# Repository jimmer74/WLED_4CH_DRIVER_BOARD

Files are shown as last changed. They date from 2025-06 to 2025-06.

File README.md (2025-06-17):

# 4 Channel WS2812B WLED driver

## Disclaimer/Licence

This project (4 Channel WS2812B WLED driver - henceforth know as "The Project") is dual licenced.

If you want to use The Project for your own personal purposes (i.e. for your own use, not for financial/commercial gain), then please feel free to use and modify it as needed. No warrentee is given and no liability is assumed by me.

If you wish to use The Project, or any aspect of it, commercially please seek my permission.  I DO NOT give consent for any of the work in The Project to be used for commercial gain by others unless with my express agreement. If terms can be agreed commercially, consent will be provided by me in writing. If you do not have such consent in writing from me, you do not have the right to use The Project, or any aspect of it, commercially.

## What is this?

I wanted a custom WS2812B board, capable of driving up to 4 strips.

I have some decent Meanwell +5v high-current PSUs on hand, and this board is designed to be fed by something like that. There's a distinct lack of overcurrent protection (apart from the obvious 5mmx20mm fuse for whole board and a 5A LF resettable fuse/channel) and I'm relying on a well-made and well-specced power supply for the rest. There's no reverse voltage protection, for instance, but the PWR_IN connector is clearly marked which end is which!

A custom build of WLED including the multirelay usermod will be needed, to make this board work. I'll probably get round to updating this readme with instructions/config at some point.

If you make up a jst-xh 1x5 connector and wire it to a INMP441 microphone off-board somewhere, then you can activate the Audioreactive usermod and enjoy some beats-driven lighting.

## Board 3d Render

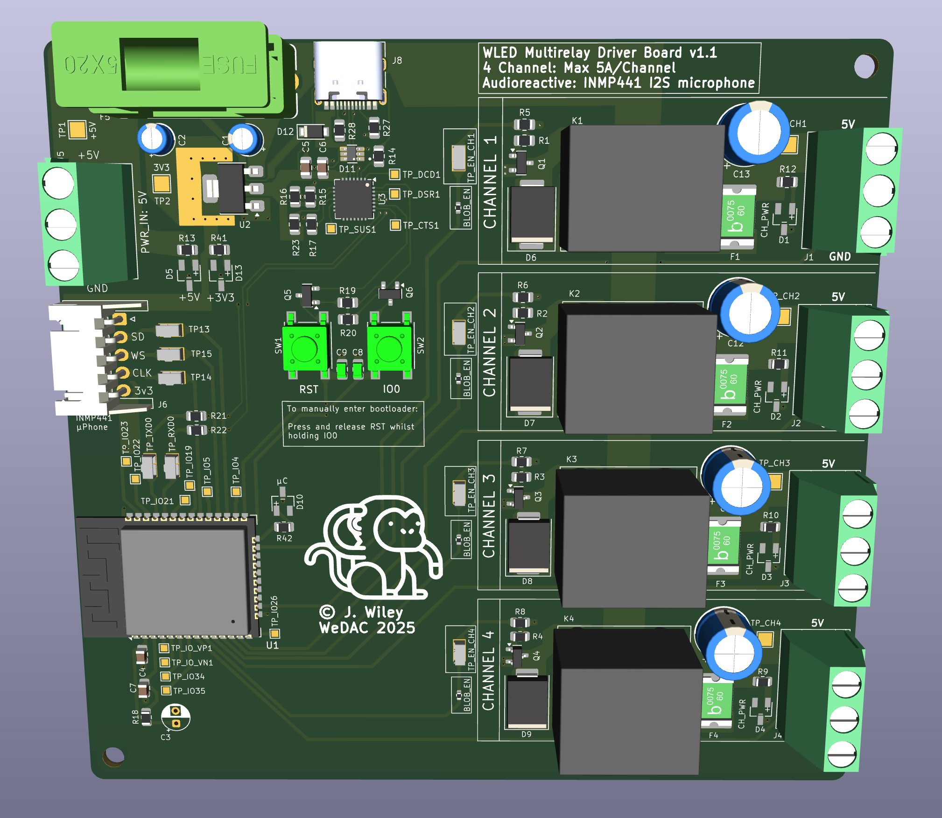
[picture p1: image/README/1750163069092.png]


## PCB Layout

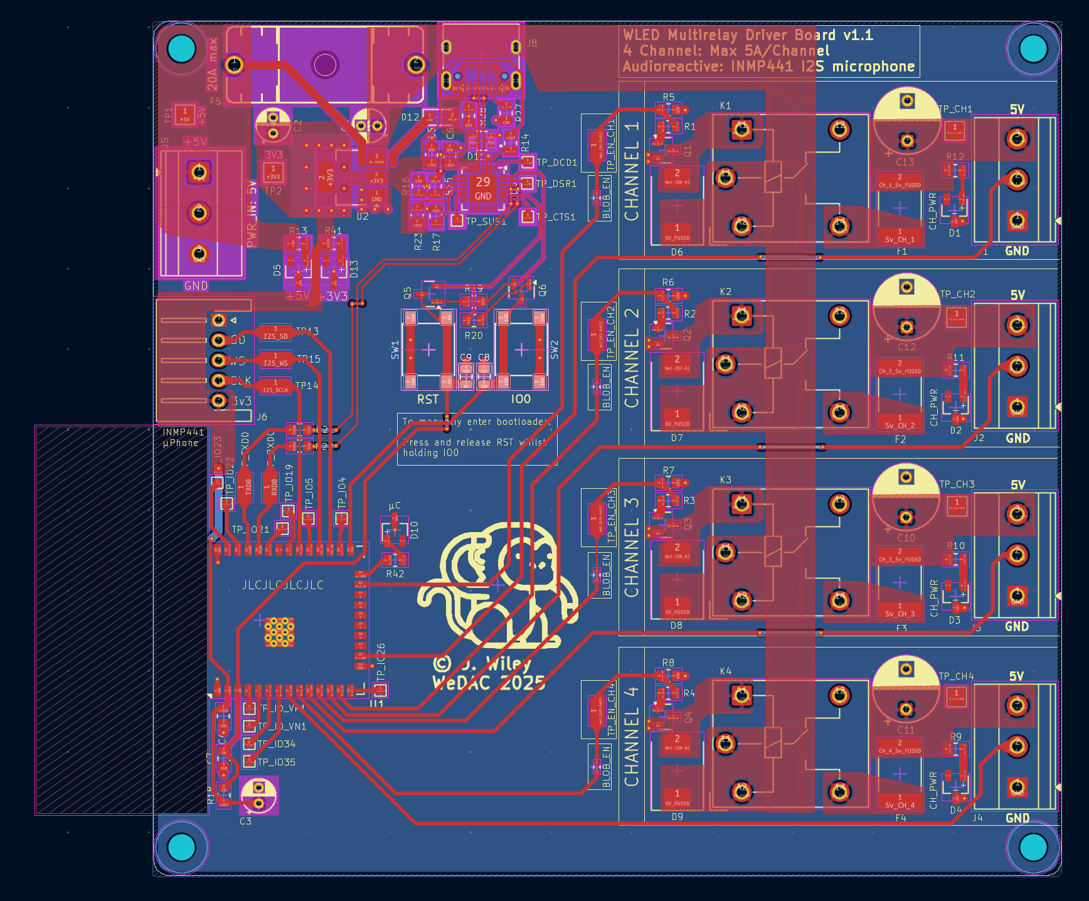
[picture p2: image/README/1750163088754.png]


## Schematic

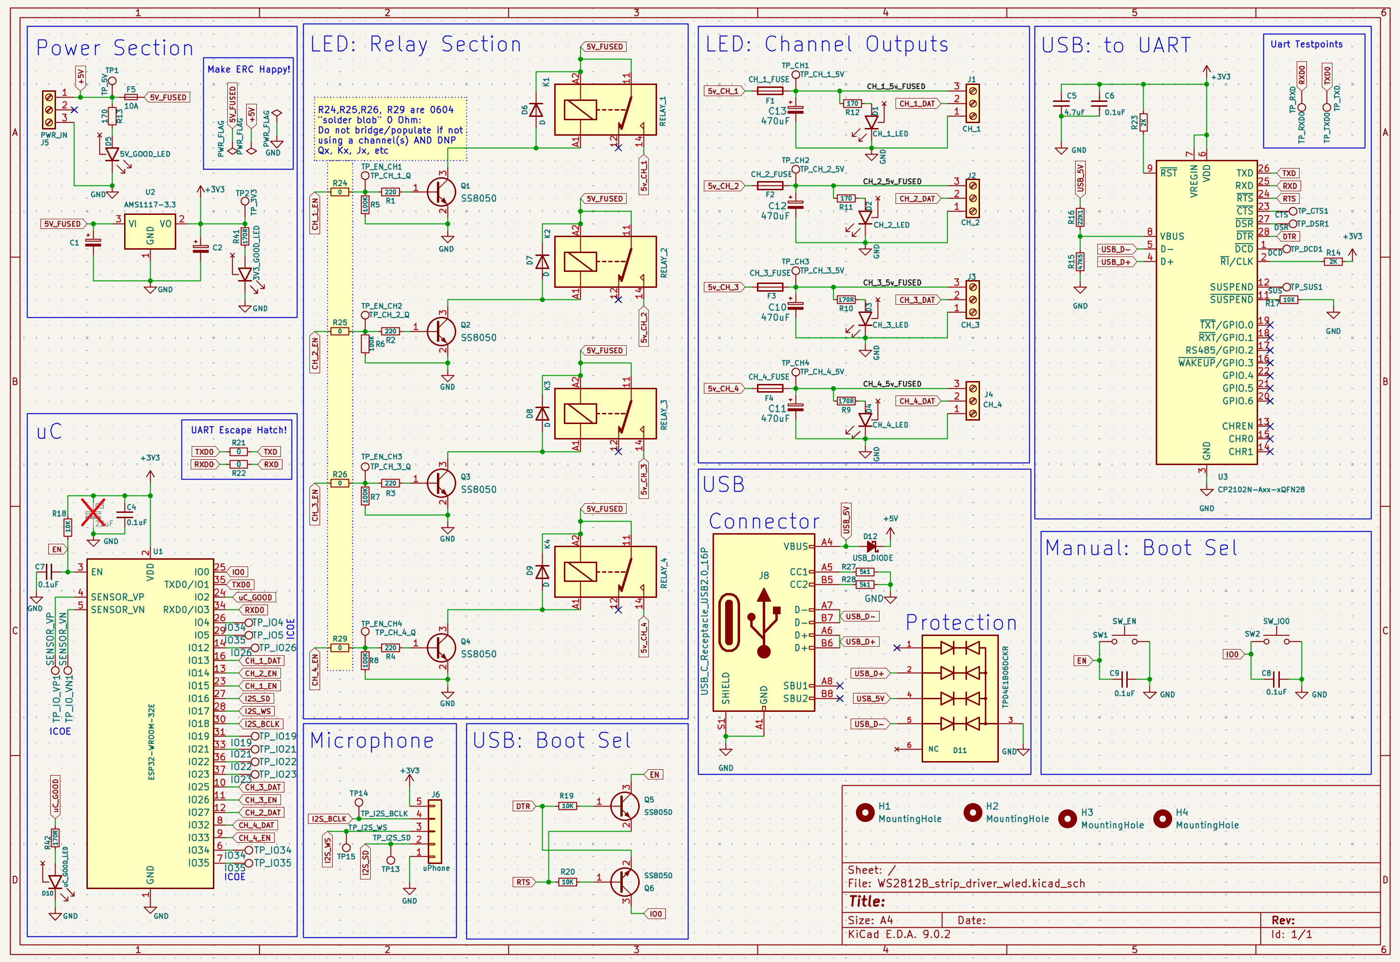
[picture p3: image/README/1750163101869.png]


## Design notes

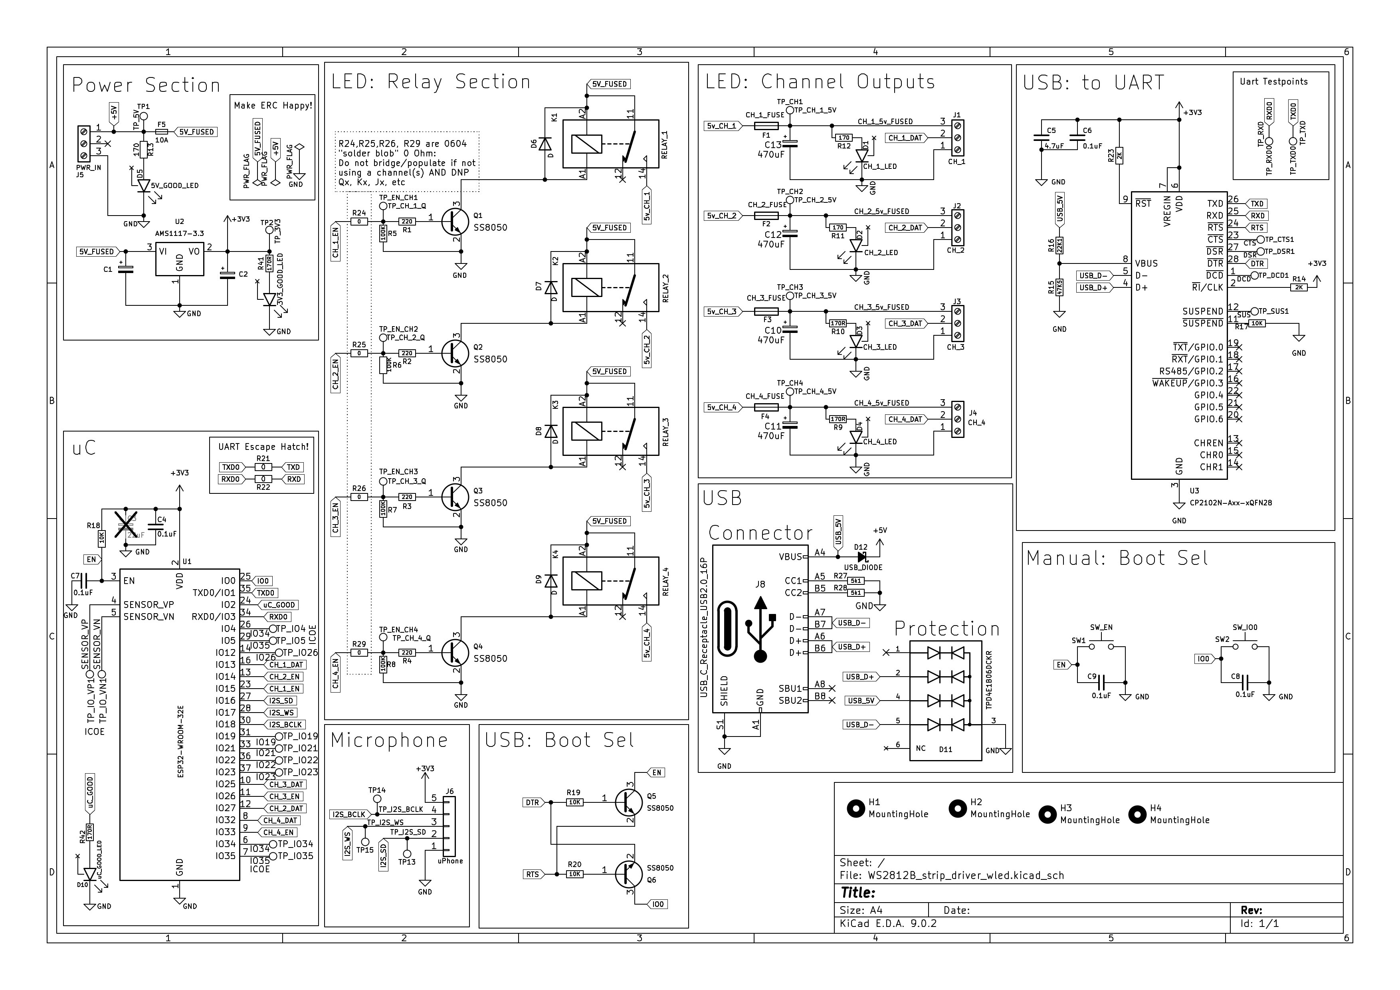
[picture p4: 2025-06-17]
wled_4ch_schematic_bnw.jpg

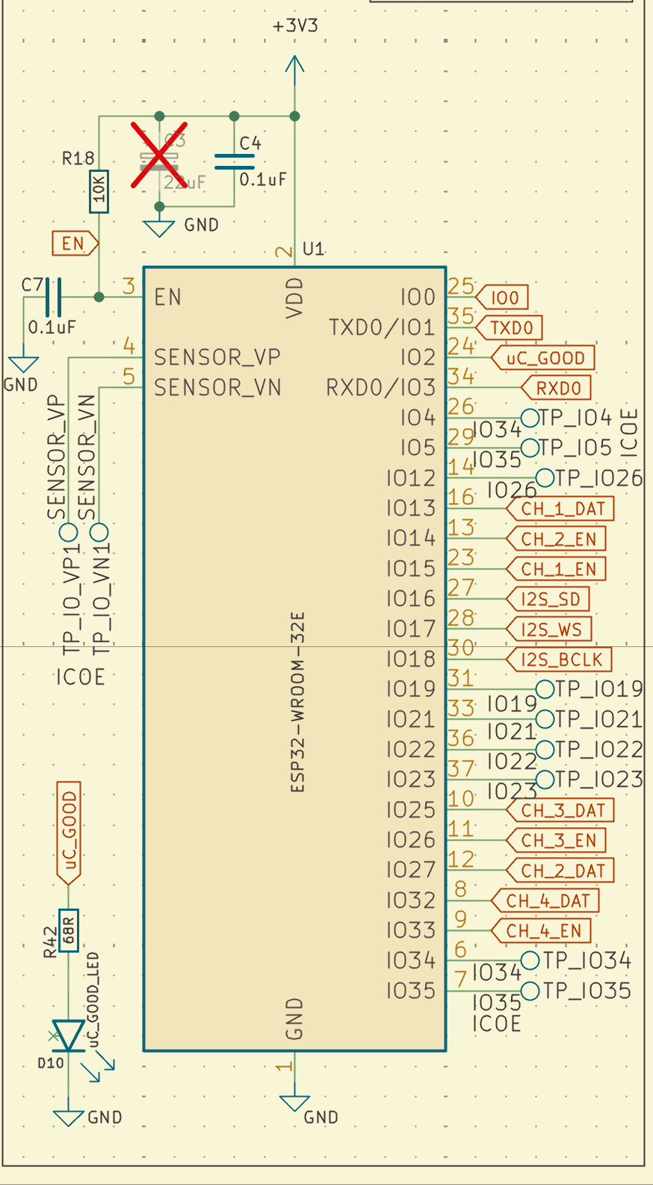
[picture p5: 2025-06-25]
wled_connections.png

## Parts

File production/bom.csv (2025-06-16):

Designator | Footprint | Quantity | Value | LCSC Part #
C1, C2 | CP_Radial_D4.0mm_P2.00mm | 2 | 22uF
C10, C11, C12, C13 | CP_Radial_D8.0mm_P5.00mm | 4 | 470uF
C4, C6, C7, C8, C9 | 0805 | 5 | 0.1uF
C5 | 0805 | 1 | 4.7uF
D1 | LED_Single_SOT23_Lumex | 1 | CH_1_LED
D10 | LED_Single_SOT23_Lumex | 1 | uC_GOOD_LED
D11 | TVS_TPD4E1B06DCKR | 1 | TPD4E1B06DCKR
D12 | Nexperia_CFP3_SOD-123W | 1 | USB_DIODE
D13 | LED_Single_SOT23_Lumex | 1 | 3V3_GOOD_LED
D2 | LED_Single_SOT23_Lumex | 1 | CH_2_LED
D3 | LED_Single_SOT23_Lumex | 1 | CH_3_LED
D4 | LED_Single_SOT23_Lumex | 1 | CH_4_LED
D5 | LED_Single_SOT23_Lumex | 1 | 5V_GOOD_LED
D6, D7, D8, D9 | D_SMC | 4 | D
F1 | 2920 | 1 | CH_1_FUSE
F2 | 2920 | 1 | CH_2_FUSE
F3 | 2920 | 1 | CH_3_FUSE
F4 | 2920 | 1 | CH_4_FUSE
F5 | Wurth_696_Fuseholder | 1 | 10A
J1 | TerminalBlock_Phoenix_MKDS-1,5-3-5.08_1x03_P5.08mm_Horizontal | 1 | CH_1
J2 | TerminalBlock_Phoenix_MKDS-1,5-3-5.08_1x03_P5.08mm_Horizontal | 1 | CH_2
J3 | TerminalBlock_Phoenix_MKDS-1,5-3-5.08_1x03_P5.08mm_Horizontal | 1 | CH_3
J4 | TerminalBlock_Phoenix_MKDS-1,5-3-5.08_1x03_P5.08mm_Horizontal | 1 | CH_4
J5 | TerminalBlock_Phoenix_MKDS-1,5-3-5.08_1x03_P5.08mm_Horizontal | 1 | PWR_IN
J6 | JST_XH_S5B-XH-A-1_1x05_P2.50mm_Horizontal | 1 | uPhone
J8 | USB_C_Receptacle_HRO_TYPE-C-31-M-12 | 1 | USB_C_Receptacle_USB2.0_16P
K1 | Relay_SPDT_Hongfa_JQC-3FF_0XX-1Z | 1 | RELAY_1
K2 | Relay_SPDT_Hongfa_JQC-3FF_0XX-1Z | 1 | RELAY_2
K3 | Relay_SPDT_Hongfa_JQC-3FF_0XX-1Z | 1 | RELAY_3
K4 | Relay_SPDT_Hongfa_JQC-3FF_0XX-1Z | 1 | RELAY_4
Q1, Q2, Q3, Q4, Q5, Q6 | SOT-23 | 6 | SS8050
R1, R2, R3, R4 | 0805 | 4 | 220
R10, R42, R9 | 0805 | 3 | 170R
R11, R12, R13, R41 | 0805 | 4 | 170
R14, R23 | 0805 | 2 | 2K
R15 | 0805 | 1 | 47K5
R16 | 0805 | 1 | 22K1
R17, R18, R19, R20 | 0805 | 4 | 10K
R21, R22 | 0805 | 2 | 0
R24, R25, R26, R29 | 0402 | 4 | 0
R27, R28 | 0805 | 2 | 5k1
R5, R6, R7, R8 | 0805 | 4 | 100K
SW1 | SW_SPST_PTS645 | 1 | SW_EN
SW2 | SW_SPST_PTS645 | 1 | SW_IO0
TP1 | TestPoint_Pad_2.0x2.0mm | 1 | TP_5V
TP13 | TESTPOINT_SMD_HARWIN_EZ_BOARDWARE_3.45X1.85mm | 1 | TP_I2S_SD
TP14 | TESTPOINT_SMD_HARWIN_EZ_BOARDWARE_3.45X1.85mm | 1 | TP_I2S_BCLK
TP15 | TESTPOINT_SMD_HARWIN_EZ_BOARDWARE_3.45X1.85mm | 1 | TP_I2S_WS
TP2 | TestPoint_Pad_2.0x2.0mm | 1 | TP_3V3
TP_CH1 | TestPoint_Pad_2.0x2.0mm | 1 | TP_CH_1_5V
TP_CH2 | TestPoint_Pad_2.0x2.0mm | 1 | TP_CH_2_5V
TP_CH3 | TestPoint_Pad_2.0x2.0mm | 1 | TP_CH_3_5V
TP_CH4 | TestPoint_Pad_2.0x2.0mm | 1 | TP_CH_4_5V
TP_CTS1 | TestPoint_Pad_1.0x1.0mm | 1 | CTS
TP_DCD1 | TestPoint_Pad_1.0x1.0mm | 1 | DCD
TP_DSR1 | TestPoint_Pad_1.0x1.0mm | 1 | DSR
TP_EN_CH1 | TESTPOINT_SMD_HARWIN_EZ_BOARDWARE_3.45X1.85mm | 1 | TP_CH_1_Q
TP_EN_CH2 | TESTPOINT_SMD_HARWIN_EZ_BOARDWARE_3.45X1.85mm | 1 | TP_CH_2_Q
TP_EN_CH3 | TESTPOINT_SMD_HARWIN_EZ_BOARDWARE_3.45X1.85mm | 1 | TP_CH_3_Q
TP_EN_CH4 | TESTPOINT_SMD_HARWIN_EZ_BOARDWARE_3.45X1.85mm | 1 | TP_CH_4_Q
TP_IO19 | TestPoint_Pad_1.0x1.0mm | 1 | IO19
TP_IO21 | TestPoint_Pad_1.0x1.0mm | 1 | IO21
TP_IO22 | TestPoint_Pad_1.0x1.0mm | 1 | IO22
TP_IO23 | TestPoint_Pad_1.0x1.0mm | 1 | IO23
TP_IO26 | TestPoint_Pad_1.0x1.0mm | 1 | IO26
TP_IO34, TP_IO4 | TestPoint_Pad_1.0x1.0mm | 2 | IO34
TP_IO35, TP_IO5 | TestPoint_Pad_1.0x1.0mm | 2 | IO35
TP_IO_VN1 | TestPoint_Pad_1.0x1.0mm | 1 | SENSOR_VN
TP_IO_VP1 | TestPoint_Pad_1.0x1.0mm | 1 | SENSOR_VP
TP_RXD0 | TESTPOINT_SMD_HARWIN_EZ_BOARDWARE_3.45X1.85mm | 1 | TP_RXD
TP_SUS1 | TestPoint_Pad_1.0x1.0mm | 1 | SUS
TP_TXD0 | TESTPOINT_SMD_HARWIN_EZ_BOARDWARE_3.45X1.85mm | 1 | TP_TXD
U1 | ESP32-WROOM-32E | 1 | ESP32-WROOM-32E
U2 | SOT-223-3_TabPin2 | 1 | AMS1117-3.3
U3 | QFN-28-1EP_5x5mm_P0.5mm_EP3.35x3.35mm | 1 | CP2102N-Axx-xQFN28

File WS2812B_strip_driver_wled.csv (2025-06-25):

Reference | Qty | Value | DNP | Exclude from BOM | Exclude from Board | Footprint | Datasheet
C1,C2 | 2 | 22uF |  |  |  | Capacitor_THT:CP_Radial_D4.0mm_P2.00mm | ~
C3 | 1 | 22uF | DNP | Excluded from BOM |  | Capacitor_THT:CP_Radial_D4.0mm_P2.00mm | ~
C4,C6,C7,C8,C9 | 5 | 0.1uF |  |  |  | Capacitor_SMD:C_0805_2012Metric | ~
C5 | 1 | 4.7uF |  |  |  | Capacitor_SMD:C_0805_2012Metric | ~
C10,C11,C12,C13 | 4 | 470uF |  |  |  | Capacitor_THT:CP_Radial_D8.0mm_P5.00mm | ~
D1 | 1 | CH_1_LED |  |  |  | SMD_LEDS_CUSTOM:LED_Single_SOT23_Lumex | ~
D2 | 1 | CH_2_LED |  |  |  | SMD_LEDS_CUSTOM:LED_Single_SOT23_Lumex | ~
D3 | 1 | CH_3_LED |  |  |  | SMD_LEDS_CUSTOM:LED_Single_SOT23_Lumex | ~
D4 | 1 | CH_4_LED |  |  |  | SMD_LEDS_CUSTOM:LED_Single_SOT23_Lumex | ~
D5 | 1 | 5V_GOOD_LED |  |  |  | SMD_LEDS_CUSTOM:LED_Single_SOT23_Lumex | ~
D6,D7,D8,D9 | 4 | D |  |  |  | Diode_SMD:D_SMC | ~
D10 | 1 | uC_GOOD_LED |  |  |  | SMD_LEDS_CUSTOM:LED_Single_SOT23_Lumex | ~
D11 | 1 | TPD4E1B06DCKR |  |  |  | CUSTOM_DIODES:TVS_TPD4E1B06DCKR
D12 | 1 | USB_DIODE |  |  |  | Diode_SMD:Nexperia_CFP3_SOD-123W | ~
D13 | 1 | 3V3_GOOD_LED |  |  |  | SMD_LEDS_CUSTOM:LED_Single_SOT23_Lumex | ~
F1 | 1 | CH_1_FUSE |  |  |  | Fuse:Fuse_2920_7451Metric | ~
F2 | 1 | CH_2_FUSE |  |  |  | Fuse:Fuse_2920_7451Metric | ~
F3 | 1 | CH_3_FUSE |  |  |  | Fuse:Fuse_2920_7451Metric | ~
F4 | 1 | CH_4_FUSE |  |  |  | Fuse:Fuse_2920_7451Metric | ~
F5 | 1 | 10A |  |  |  | Fuseholder_PCB_Mount:Wurth_696_Fuseholder | ~
H1,H2,H3,H4 | 4 | MountingHole |  | Excluded from BOM |  | MountingHole:MountingHole_3.2mm_M3 | ~
J1 | 1 | CH_1 |  |  |  | TerminalBlock_Phoenix:TerminalBlock_Phoenix_MKDS-1,5-3-5.08_1x03_P5.08mm_Horizontal | ~
J2 | 1 | CH_2 |  |  |  | TerminalBlock_Phoenix:TerminalBlock_Phoenix_MKDS-1,5-3-5.08_1x03_P5.08mm_Horizontal | ~
J3 | 1 | CH_3 |  |  |  | TerminalBlock_Phoenix:TerminalBlock_Phoenix_MKDS-1,5-3-5.08_1x03_P5.08mm_Horizontal | ~
J4 | 1 | CH_4 |  |  |  | TerminalBlock_Phoenix:TerminalBlock_Phoenix_MKDS-1,5-3-5.08_1x03_P5.08mm_Horizontal | ~
J5 | 1 | PWR_IN |  |  |  | TerminalBlock_Phoenix:TerminalBlock_Phoenix_MKDS-1,5-3-5.08_1x03_P5.08mm_Horizontal | ~
J6 | 1 | uPhone |  |  |  | Connector_JST:JST_XH_S5B-XH-A-1_1x05_P2.50mm_Horizontal | ~
J8 | 1 | USB_C_Receptacle_USB2.0_16P |  |  |  | Connector_USB:USB_C_Receptacle_HRO_TYPE-C-31-M-12 | https://www.usb.org/sites/default/files/documents/usb_type-c.zip
K1 | 1 | RELAY_1 |  |  |  | Relay_THT:Relay_SPDT_Hongfa_JQC-3FF_0XX-1Z | https://www.digikey.com/htmldatasheets/production/2071105/0/0/1/JQC-3FF.pdf
K2 | 1 | RELAY_2 |  |  |  | Relay_THT:Relay_SPDT_Hongfa_JQC-3FF_0XX-1Z | https://www.digikey.com/htmldatasheets/production/2071105/0/0/1/JQC-3FF.pdf
K3 | 1 | RELAY_3 |  |  |  | Relay_THT:Relay_SPDT_Hongfa_JQC-3FF_0XX-1Z | https://www.digikey.com/htmldatasheets/production/2071105/0/0/1/JQC-3FF.pdf
K4 | 1 | RELAY_4 |  |  |  | Relay_THT:Relay_SPDT_Hongfa_JQC-3FF_0XX-1Z | https://www.digikey.com/htmldatasheets/production/2071105/0/0/1/JQC-3FF.pdf
Q1,Q2,Q3,Q4,Q5,Q6 | 6 | SS8050 |  |  |  | Package_TO_SOT_SMD:SOT-23 | http://www.secosgmbh.com/datasheet/products/SSMPTransistor/SOT-23/SS8050.pdf
R1,R2,R3,R4 | 4 | 220 |  |  |  | Resistor_SMD:R_0805_2012Metric | ~
R5,R6,R7,R8 | 4 | 100K |  |  |  | Resistor_SMD:R_0805_2012Metric | ~
R9,R10,R41,R42 | 4 | 170R |  |  |  | Resistor_SMD:R_0805_2012Metric | ~
R11,R12,R13 | 3 | 170 |  |  |  | Resistor_SMD:R_0805_2012Metric | ~
R14,R23 | 2 | 2K |  |  |  | Resistor_SMD:R_0805_2012Metric | ~
R15 | 1 | 47K5 |  |  |  | Resistor_SMD:R_0805_2012Metric | ~
R16 | 1 | 22K1 |  |  |  | Resistor_SMD:R_0805_2012Metric | ~
R17,R18,R19,R20 | 4 | 10K |  |  |  | Resistor_SMD:R_0805_2012Metric | ~
R21,R22 | 2 | 0 |  |  |  | Resistor_SMD:R_0805_2012Metric | ~
R24,R25,R26,R29 | 4 | 0 |  |  |  | Resistor_SMD:R_0402_1005Metric | ~
R27,R28 | 2 | 5k1 |  |  |  | Resistor_SMD:R_0805_2012Metric | ~
SW1 | 1 | SW_EN |  |  |  | Button_Switch_SMD:SW_SPST_PTS645 | ~
SW2 | 1 | SW_IO0 |  |  |  | Button_Switch_SMD:SW_SPST_PTS645 | ~
TP1 | 1 | TP_5V |  |  |  | TestPoint:TestPoint_Pad_2.0x2.0mm | ~
TP2 | 1 | TP_3V3 |  |  |  | TestPoint:TestPoint_Pad_2.0x2.0mm | ~
TP13 | 1 | TP_I2S_SD |  |  |  | TESTPOINT_SMD:TESTPOINT_SMD_HARWIN_EZ_BOARDWARE_3.45X1.85mm | ~
TP14 | 1 | TP_I2S_BCLK |  |  |  | TESTPOINT_SMD:TESTPOINT_SMD_HARWIN_EZ_BOARDWARE_3.45X1.85mm | ~
TP15 | 1 | TP_I2S_WS |  |  |  | TESTPOINT_SMD:TESTPOINT_SMD_HARWIN_EZ_BOARDWARE_3.45X1.85mm | ~
TP_CH1 | 1 | TP_CH_1_5V |  |  |  | TestPoint:TestPoint_Pad_2.0x2.0mm | ~
TP_CH2 | 1 | TP_CH_2_5V |  |  |  | TestPoint:TestPoint_Pad_2.0x2.0mm | ~
TP_CH3 | 1 | TP_CH_3_5V |  |  |  | TestPoint:TestPoint_Pad_2.0x2.0mm | ~
TP_CH4 | 1 | TP_CH_4_5V |  |  |  | TestPoint:TestPoint_Pad_2.0x2.0mm | ~
TP_CTS1 | 1 | CTS |  |  |  | TestPoint:TestPoint_Pad_1.0x1.0mm | ~
TP_DCD1 | 1 | DCD |  |  |  | TestPoint:TestPoint_Pad_1.0x1.0mm | ~
TP_DSR1 | 1 | DSR |  |  |  | TestPoint:TestPoint_Pad_1.0x1.0mm | ~
TP_EN_CH1 | 1 | TP_CH_1_Q |  |  |  | TESTPOINT_SMD:TESTPOINT_SMD_HARWIN_EZ_BOARDWARE_3.45X1.85mm | ~
TP_EN_CH2 | 1 | TP_CH_2_Q |  |  |  | TESTPOINT_SMD:TESTPOINT_SMD_HARWIN_EZ_BOARDWARE_3.45X1.85mm | ~
TP_EN_CH3 | 1 | TP_CH_3_Q |  |  |  | TESTPOINT_SMD:TESTPOINT_SMD_HARWIN_EZ_BOARDWARE_3.45X1.85mm | ~
TP_EN_CH4 | 1 | TP_CH_4_Q |  |  |  | TESTPOINT_SMD:TESTPOINT_SMD_HARWIN_EZ_BOARDWARE_3.45X1.85mm | ~
TP_IO4,TP_IO34 | 2 | IO34 |  |  |  | TestPoint:TestPoint_Pad_1.0x1.0mm | ~
TP_IO5,TP_IO35 | 2 | IO35 |  |  |  | TestPoint:TestPoint_Pad_1.0x1.0mm | ~
TP_IO19 | 1 | IO19 |  |  |  | TestPoint:TestPoint_Pad_1.0x1.0mm | ~
TP_IO21 | 1 | IO21 |  |  |  | TestPoint:TestPoint_Pad_1.0x1.0mm | ~
TP_IO22 | 1 | IO22 |  |  |  | TestPoint:TestPoint_Pad_1.0x1.0mm | ~
TP_IO23 | 1 | IO23 |  |  |  | TestPoint:TestPoint_Pad_1.0x1.0mm | ~
TP_IO26 | 1 | IO26 |  |  |  | TestPoint:TestPoint_Pad_1.0x1.0mm | ~
TP_IO_VN1 | 1 | SENSOR_VN |  |  |  | TestPoint:TestPoint_Pad_1.0x1.0mm | ~
TP_IO_VP1 | 1 | SENSOR_VP |  |  |  | TestPoint:TestPoint_Pad_1.0x1.0mm | ~
TP_RXD0 | 1 | TP_RXD |  |  |  | TESTPOINT_SMD:TESTPOINT_SMD_HARWIN_EZ_BOARDWARE_3.45X1.85mm | ~
TP_SUS1 | 1 | SUS |  |  |  | TestPoint:TestPoint_Pad_1.0x1.0mm | ~
TP_TXD0 | 1 | TP_TXD |  |  |  | TESTPOINT_SMD:TESTPOINT_SMD_HARWIN_EZ_BOARDWARE_3.45X1.85mm | ~
U1 | 1 | ESP32-WROOM-32E |  |  |  | JIMS_MCUS:ESP32-WROOM-32E-0.3VIAS | https://www.espressif.com/sites/default/files/documentation/esp32-wroom-32e_esp32-wroom-32ue_datasheet_en.pdf
U2 | 1 | AMS1117-3.3 |  |  |  | Package_TO_SOT_SMD:SOT-223-3_TabPin2 | http://www.advanced-monolithic.com/pdf/ds1117.pdf
U3 | 1 | CP2102N-Axx-xQFN28 |  |  |  | Package_DFN_QFN:QFN-28-1EP_5x5mm_P0.5mm_EP3.35x3.35mm | https://www.silabs.com/documents/public/data-sheets/cp2102n-datasheet.pdf

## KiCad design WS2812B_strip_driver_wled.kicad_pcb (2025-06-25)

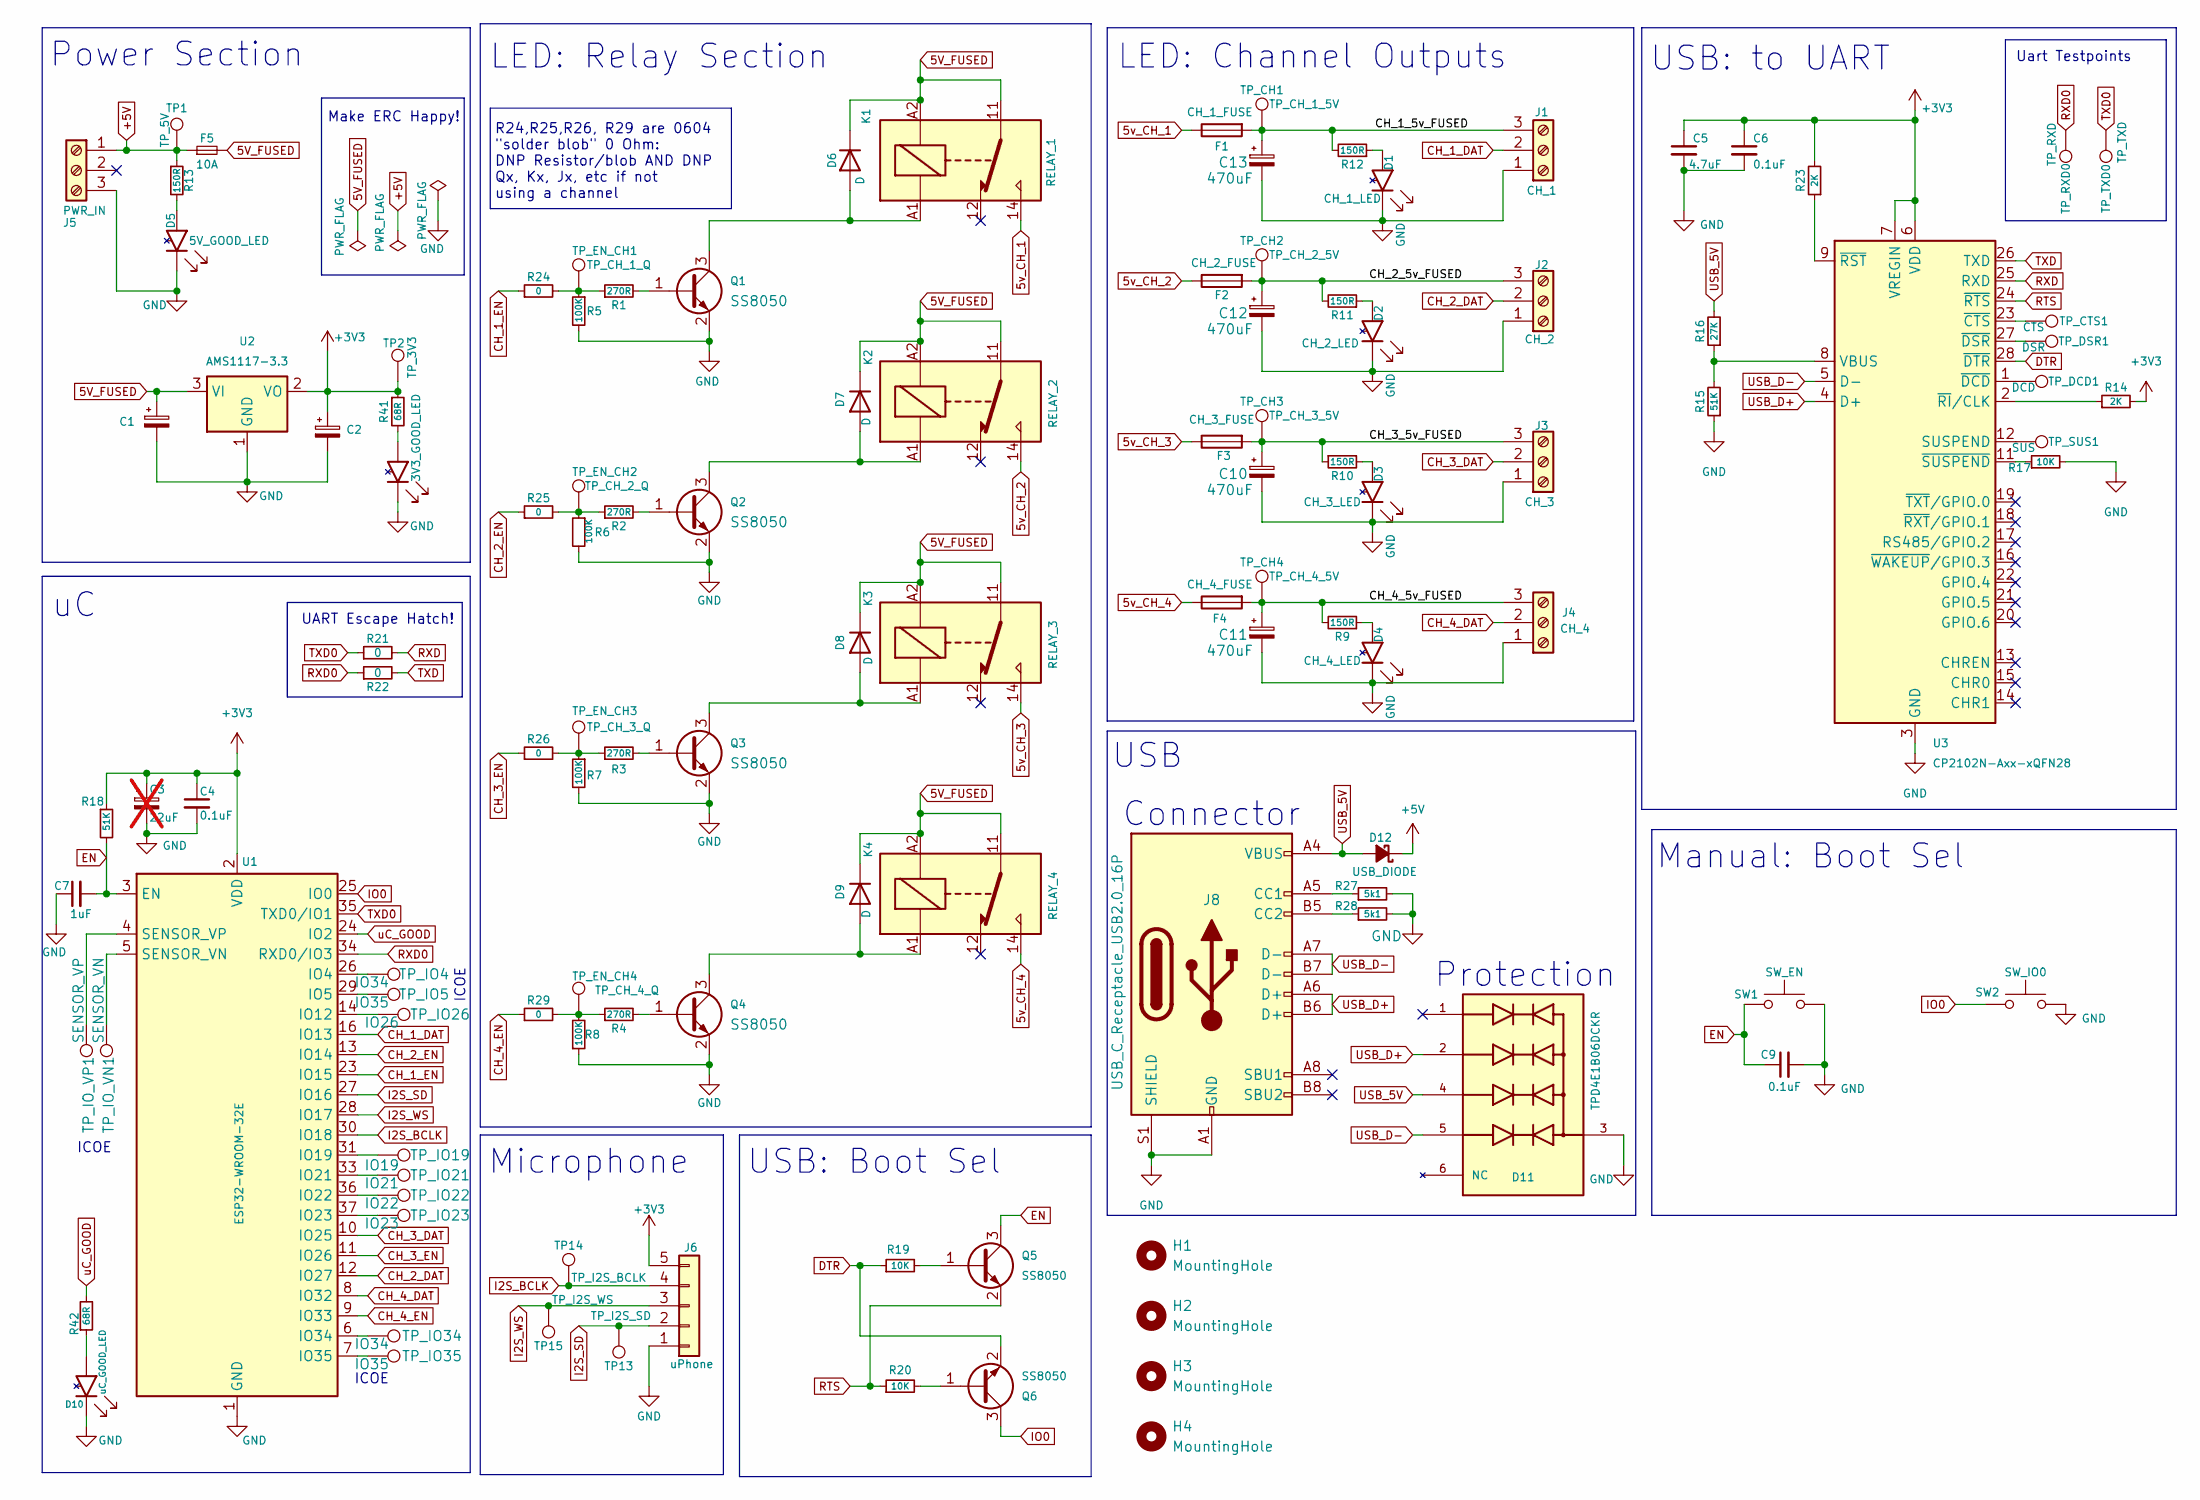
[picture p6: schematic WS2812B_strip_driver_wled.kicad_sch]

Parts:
C1, C2: 22uF; CP_Radial_D4.0mm_P2.00mm
C3: 22uF; CP_Radial_D4.0mm_P2.00mm; not fitted
C4, C6, C9: 0.1uF; C_0805_2012Metric
C5: 4.7uF; C_0805_2012Metric
C7: 1uF; C_0805_2012Metric
C10, C11, C12, C13: 470uF; CP_Radial_D8.0mm_P5.00mm
D1: CH_1_LED; LED_Single_SOT23_Lumex
D2: CH_2_LED; LED_Single_SOT23_Lumex
D3: CH_3_LED; LED_Single_SOT23_Lumex
D4: CH_4_LED; LED_Single_SOT23_Lumex
D5: 5V_GOOD_LED; LED_Single_SOT23_Lumex
D6, D7, D8, D9: D; D_SMC
D10: uC_GOOD_LED; LED_Single_SOT23_Lumex
D11: TPD4E1B06DCKR; TVS_TPD4E1B06DCKR
D12: USB_DIODE; Nexperia_CFP3_SOD-123W
D13: 3V3_GOOD_LED; LED_Single_SOT23_Lumex
F1: CH_1_FUSE; Fuse_2920_7451Metric
F2: CH_2_FUSE; Fuse_2920_7451Metric
F3: CH_3_FUSE; Fuse_2920_7451Metric
F4: CH_4_FUSE; Fuse_2920_7451Metric
F5: 10A; Wurth_696_Fuseholder
H1, H2, H3, H4: MountingHole; MountingHole_3.2mm_M3
J1: CH_1; TerminalBlock_Phoenix_MKDS-1,5-3-5.08_1x03_P5.08mm_Horizont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
J2: CH_2; TerminalBlock_Phoenix_MKDS-1,5-3-5.08_1x03_P5.08mm_Horizont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
J3: CH_3; TerminalBlock_Phoenix_MKDS-1,5-3-5.08_1x03_P5.08mm_Horizont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
J4: CH_4; TerminalBlock_Phoenix_MKDS-1,5-3-5.08_1x03_P5.08mm_Horizont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
J5: PWR_IN; TerminalBlock_Phoenix_MKDS-1,5-3-5.08_1x03_P5.08mm_Horizont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
J6: uPhone; JST_XH_S5B-XH-A-1_1x05_P2.50mm_Horizontal
J8: USB_C_Receptacle_USB2.0_16P; USB_C_Receptacle_HRO_TYPE-C-31-M-12
K1: RELAY_1; Relay_SPDT_Hongfa_JQC-3FF_0XX-1Z
K2: RELAY_2; Relay_SPDT_Hongfa_JQC-3FF_0XX-1Z
K3: RELAY_3; Relay_SPDT_Hongfa_JQC-3FF_0XX-1Z
K4: RELAY_4; Relay_SPDT_Hongfa_JQC-3FF_0XX-1Z
Q1, Q2, Q3, Q4, Q5, Q6: SS8050; SOT-23
R1, R2, R3, R4: 270R; R_0805_2012Metric
R5, R6, R7, R8: 100K; R_0805_2012Metric
R9, R10, R11, R12, R13: 150R; R_0805_2012Metric
R14, R23: 2K; R_0805_2012Metric
R15, R18: 51K; R_0805_2012Metric
R16: 27K; R_0805_2012Metric
R17, R19, R20: 10K; R_0805_2012Metric
R21, R22: 0; R_0805_2012Metric
R24, R25, R26, R29: 0; R_0402_1005Metric
R27, R28: 5k1; R_0805_2012Metric
R41, R42: 68R; R_0805_2012Metric
SW1: SW_EN; SW_SPST_PTS645
SW2: SW_IO0; SW_SPST_PTS645
TP1: TP_5V; TestPoint_Pad_2.0x2.0mm
TP2: TP_3V3; TestPoint_Pad_2.0x2.0mm
TP13: TP_I2S_SD; TESTPOINT_SMD_HARWIN_EZ_BOARDWARE_3.45X1.85mm
TP14: TP_I2S_BCLK; TESTPOINT_SMD_HARWIN_EZ_BOARDWARE_3.45X1.85mm
TP15: TP_I2S_WS; TESTPOINT_SMD_HARWIN_EZ_BOARDWARE_3.45X1.85mm
TP_CH1: TP_CH_1_5V; TestPoint_Pad_2.0x2.0mm
TP_CH2: TP_CH_2_5V; TestPoint_Pad_2.0x2.0mm
TP_CH3: TP_CH_3_5V; TestPoint_Pad_2.0x2.0mm
TP_CH4: TP_CH_4_5V; TestPoint_Pad_2.0x2.0mm
TP_CTS1: CTS; TestPoint_Pad_1.0x1.0mm
TP_DCD1: DCD; TestPoint_Pad_1.0x1.0mm
TP_DSR1: DSR; TestPoint_Pad_1.0x1.0mm
TP_EN_CH1: TP_CH_1_Q; TESTPOINT_SMD_HARWIN_EZ_BOARDWARE_3.45X1.85mm
TP_EN_CH2: TP_CH_2_Q; TESTPOINT_SMD_HARWIN_EZ_BOARDWARE_3.45X1.85mm
TP_EN_CH3: TP_CH_3_Q; TESTPOINT_SMD_HARWIN_EZ_BOARDWARE_3.45X1.85mm
TP_EN_CH4: TP_CH_4_Q; TESTPOINT_SMD_HARWIN_EZ_BOARDWARE_3.45X1.85mm
TP_IO4, TP_IO34: IO34; TestPoint_Pad_1.0x1.0mm
TP_IO5, TP_IO35: IO35; TestPoint_Pad_1.0x1.0mm
TP_IO19: IO19; TestPoint_Pad_1.0x1.0mm
TP_IO21: IO21; TestPoint_Pad_1.0x1.0mm
TP_IO22: IO22; TestPoint_Pad_1.0x1.0mm
TP_IO23: IO23; TestPoint_Pad_1.0x1.0mm
TP_IO26: IO26; TestPoint_Pad_1.0x1.0mm
TP_IO_VN1: SENSOR_VN; TestPoint_Pad_1.0x1.0mm
TP_IO_VP1: SENSOR_VP; TestPoint_Pad_1.0x1.0mm
TP_RXD0: TP_RXD; TESTPOINT_SMD_HARWIN_EZ_BOARDWARE_3.45X1.85mm
TP_SUS1: SUS; TestPoint_Pad_1.0x1.0mm
TP_TXD0: TP_TXD; TESTPOINT_SMD_HARWIN_EZ_BOARDWARE_3.45X1.85mm
U1: ESP32-WROOM-32E; ESP32-WROOM-32E-0.3VIAS
U2: AMS1117-3.3; SOT-223-3_TabPin2
U3: CP2102N-Axx-xQFN28; QFN-28-1EP_5x5mm_P0.5mm_EP3.35x3.35mm

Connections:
5V_FUSED: C1.1, D6.1 (K), D7.1 (K), D8.1 (K), D9.1 (K), F5.2, K1.11, K1.A2, K2.11, K2.A2, K3.11, K3.A2, K4.11, K4.A2, U2.3 (VI)
5v_CH_1: F1.1, K1.14
5v_CH_2: F2.1, K2.14
5v_CH_3: F3.1, K3.14
5v_CH_4: F4.1, K4.14
+3V3: C2.1, C3.1, C4.1, C5.1, C6.1, J6.5, R14.2, R18.1, R23.2, R41.1, TP2.1, U1.2 (VDD), U2.2 (VO), U3.6 (VDD), U3.7 (VREGIN)
+5V: D12.1 (K), F5.1, J5.1, R13.1, TP1.1
/CH_1_5v_FUSED: C13.1, F1.2, J1.3, R12.2, TP_CH1.1
/CH_2_5v_FUSED: C12.1, F2.2, J2.3, R11.2, TP_CH2.1
/CH_3_5v_FUSED: C10.1, F3.2, J3.3, R10.1, TP_CH3.1
/CH_4_5v_FUSED: C11.1, F4.2, J4.3, R9.2, TP_CH4.1
CH_1_DAT: J1.2, U1.16 (IO13)
CH_1_EN: R24.1, U1.23 (IO15)
CH_2_DAT: J2.2, U1.12 (IO27)
CH_2_EN: R25.1, U1.13 (IO14)
CH_3_DAT: J3.2, U1.10 (IO25)
CH_3_EN: R26.1, U1.11 (IO26)
CH_4_DAT: J4.2, U1.8 (IO32)
CH_4_EN: R29.1, U1.9 (IO33)
DTR: Q6.2 (E), R19.1, U3.28 (~DTR)
EN: C7.2, C9.1, Q5.3 (C), R18.2, SW1.1, U1.3 (EN)
GND: C1.2, C2.2, C3.2, C4.2, C5.2, C6.2, C7.1, C9.2, C10.2, C11.2, C12.2, C13.2, D1.3, D2.3, D3.3, D4.3, D5.3, D10.3, D11.3, D13.3, J1.1, J2.1, J3.1, J4.1, J5.3, J6.1, J8.A1 (GND), J8.A12 (GND), J8.B1 (GND), J8.B12 (GND), J8.S1 (SHIELD), Q1.2 (E), Q2.2 (E), Q3.2 (E), Q4.2 (E), R5.2, R6.2, R7.2, R8.1, R15.1, R17.2, R27.2, R28.2, SW1.2, SW2.2, U1.1 (GND), U1.15 (GND), U1.38 (GND), U1.39 (GND), U2.1 (GND), U3.3 (GND), U3.29 (GND)
I2S_BCLK: J6.4, TP14.1, U1.30 (IO18)
I2S_SD: J6.2, TP13.1, U1.27 (IO16)
I2S_WS: J6.3, TP15.1, U1.28 (IO17)
IO0: Q6.3 (C), SW2.1, U1.25 (IO0)
unnamed: D1.2, R12.1
unnamed: D2.2, R11.1
unnamed: D3.2, R10.2
unnamed: D4.2, R9.1
unnamed: D5.2, R13.2
unnamed: D6.2 (A), K1.A1, Q1.3 (C)
unnamed: D7.2 (A), K2.A1, Q2.3 (C)
unnamed: D8.2 (A), K3.A1, Q3.3 (C)
unnamed: D9.2 (A), K4.A1, Q4.3 (C)
unnamed: D10.2, R42.1
unnamed: D13.2, R41.2
unnamed: J8.A5 (CC1), R27.1
unnamed: J8.B5 (CC2), R28.1
unnamed: Q1.1 (B), R1.2
unnamed: Q2.1 (B), R2.2
unnamed: Q3.1 (B), R3.2
unnamed: Q4.1 (B), R4.2
unnamed: Q5.1 (B), R19.2
unnamed: Q6.1 (B), R20.2
unnamed: R1.1, R5.1, R24.2, TP_EN_CH1.1
unnamed: R2.1, R6.1, R25.2, TP_EN_CH2.1
unnamed: R3.1, R7.1, R26.2, TP_EN_CH3.1
unnamed: R4.1, R8.2, R29.2, TP_EN_CH4.1
unnamed: TP_IO4.1, U1.26 (IO4)
unnamed: TP_IO5.1, U1.29 (IO5)
unnamed: TP_IO26.1, U1.14 (IO12)
unnamed: TP_IO19.1, U1.31 (IO19)
unnamed: TP_IO21.1, U1.33 (IO21)
unnamed: TP_IO22.1, U1.36 (IO22)
unnamed: TP_IO23.1, U1.37 (IO23)
unnamed: TP_IO34.1, U1.6 (IO34)
unnamed: TP_IO35.1, U1.7 (IO35)
unnamed: TP_IO_VN1.1, U1.5 (SENSOR_VN)
unnamed: TP_IO_VP1.1, U1.4 (SENSOR_VP)
unnamed: TP_SUS1.1, U3.12 (SUSPEND)
unnamed: R15.2, R16.1, U3.8 (VBUS)
unnamed: TP_CTS1.1, U3.23 (~CTS)
unnamed: TP_DCD1.1, U3.1 (~DCD)
unnamed: TP_DSR1.1, U3.27 (~DSR)
unnamed: R14.1, U3.2 (~RI/CLK)
unnamed: R23.1, U3.9 (~RST)
unnamed: R17.1, U3.11 (~SUSPEND)
RTS: Q5.2 (E), R20.1, U3.24 (~RTS)
RXD: R21.2, U3.25 (RXD)
RXD0: R22.1, TP_RXD0.1, U1.34 (RXD0/IO3)
TXD: R22.2, U3.26 (TXD)
TXD0: R21.1, TP_TXD0.1, U1.35 (TXD0/IO1)
USB_5V: D11.4, D12.2 (A), J8.A4 (VBUS), J8.A9 (VBUS), J8.B4 (VBUS), J8.B9 (VBUS), R16.2
USB_D+: D11.2, J8.A6 (D+), J8.B6 (D+), U3.4 (D+)
USB_D-: D11.5, J8.A7 (D-), J8.B7 (D-), U3.5 (D-)
uC_GOOD: R42.2, U1.24 (IO2)

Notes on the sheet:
Protection
Connector
Uart Testpoints
ICOE
USB
R24,R25,R26, R29 are 0604 "solder blob" 0 Ohm: DNP Resistor/blob AND DNP Qx, Kx, Jx, etc if not using a channel
Manual: Boot Sel
Make ERC Happy!
Power Section
UART Escape Hatch!
Microphone
LED: Channel Outputs
LED: Relay Section
USB: to UART
USB: Boot Sel

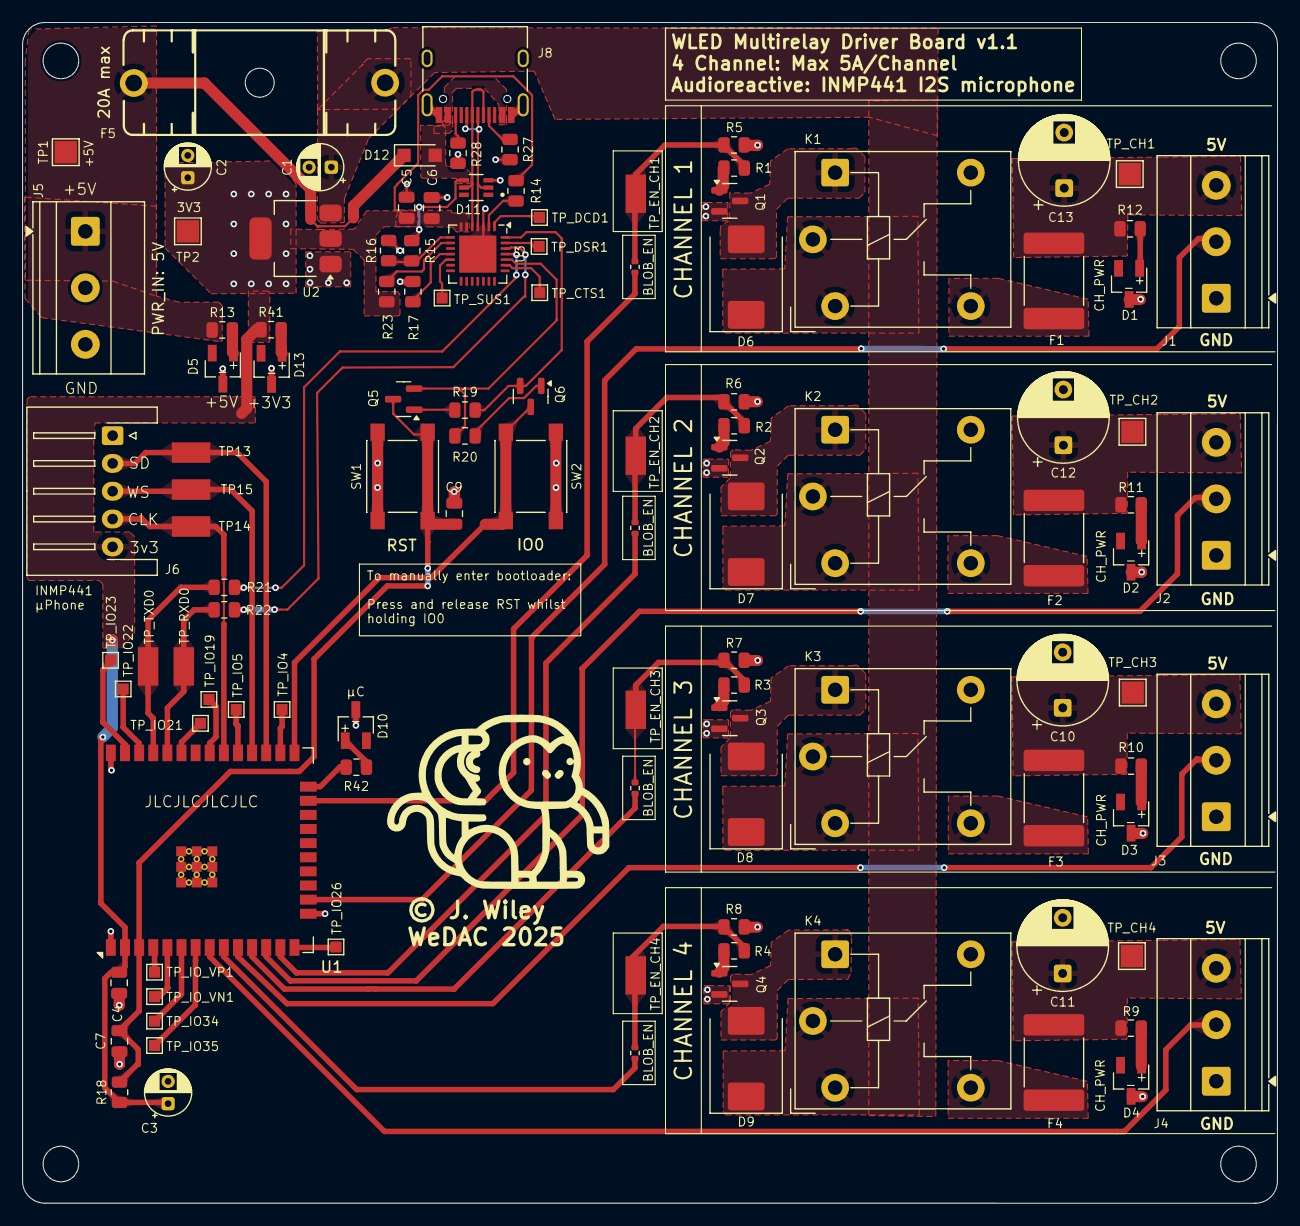
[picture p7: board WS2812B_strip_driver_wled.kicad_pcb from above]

Board: 2 copper layers, 112.9 x 106.2 mm, 117 parts (0 on the bottom side), 77 nets.

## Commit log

2025-06-15 better gitignore
    [WS2812B_strip_driver_wled.kicad_pcb]
2025-06-15 added btn labels, moved logo
    [WS2812B_strip_driver_wled.kicad_pcb]
2025-06-15 More silkscreen improvements/additions
    [WS2812B_strip_driver_wled.kicad_pcb, WS2812B_strip_driver_wled.kicad_sch]
2025-06-15 reordered channels, renamed TP's, moved uC good led
    [WS2812B_strip_driver_wled.kicad_pcb]
2025-06-15 added 0402 zero-ohm for solder-blob jumpering the channels. Even better silkscreen
    [WS2812B_strip_driver_wled.kicad_pcb, WS2812B_strip_driver_wled.kicad_sch]
2025-06-15 added JLCJLCJLCJLC to silkscreen for manual positioning under chip
    [WS2812B_strip_driver_wled.kicad_pcb]
2025-06-16 more silkscreen updates, moved pwr_in connnector slightly to allow room for better labelling
    [WS2812B_strip_driver_wled.kicad_pcb]
2025-06-16 moved testpoints, aligned channel 1, better silkscreen
    [WS2812B_strip_driver_wled.kicad_pcb]
2025-06-16 created v1.0 gerbers
    [WS2812B_strip_driver_wled-B_Courtyard.gbr, WS2812B_strip_driver_wled-B_Cu.gbl, WS2812B_strip_driver_wled-B_Fab.gbr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]
2025-06-17 removed micro vias by usb-c connection
    [WS2812B_strip_driver_wled.kicad_pcb]
2025-06-17 created v1.1 gerbers
    [WS2812B_strip_driver_wled-B_Courtyard.gbr, WS2812B_strip_driver_wled-B_Cu.gbl, WS2812B_strip_driver_wled-B_Fab.gbr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]
2025-06-17 cleaned up schematic. assigned esp32e as my custom version with 0.3mm vias to stop drc warnings
    [WS2812B_strip_driver_wled.kicad_pcb, WS2812B_strip_driver_wled.kicad_sch]
2025-06-17 updated readme with licence info, brief description and some images
    [WS2812B_strip_driver_wled.kicad_sch]
2025-06-25 swapped incorrect rx/tx pins
    [WS2812B_strip_driver_wled.csv, WS2812B_strip_driver_wled.kicad_pcb, WS2812B_strip_driver_wled.kicad_sch]
2025-06-25 swapped change en rc circuit vals, removed io btn debouncing cap. Board now fires straight up
    [WS2812B_strip_driver_wled.kicad_pcb, WS2812B_strip_driver_wled.kicad_sch]

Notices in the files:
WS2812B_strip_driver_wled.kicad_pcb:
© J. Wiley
